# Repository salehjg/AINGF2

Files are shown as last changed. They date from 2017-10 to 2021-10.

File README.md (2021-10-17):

# AINGF2
FPGA Based Digital Still Camera Over USB-2.0  
  
# Hardware
FPGA: Xilinx Spartan-3  
Memory: Cypress SRAM * 2 (seperate busses)  
USB: Cypress USBFX2LP  
  
# Architecture
* Ping-pong frame aquisition by utilizing the both SRAMs and their respective (and seperate) SRAM Controllers 
* 8051 soft-core for reset signal management and I3C custom interface handling.  
* simple hex2coef converter utility to convert built firmware(hex-file) into xilinx-coef format for integrating into ROM IP CORE (on platform-flash)  
  
# PCB
Designed using Altium-Designer as double-sided PCB.  
there are some known issues related to ground bouncing and signal integrity at challenging clock frequencies (PCLK, main clock) which are avoidable by a proper 4-Layer PCB stackup.  
  
# Software
The host program is written in C#.Net to receive data that is sent over USB-2 and to configure the internal registers of the image sensor based on the official SDK for USBFX2LP and the official Cypress driver for Microsoft-Windows.

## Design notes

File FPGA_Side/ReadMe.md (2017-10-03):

# FPGA Side
**Tool:** 		Xilinx ISE 14.7  
**Board:** 		AINGF-V2(PCB project is included in this repository)  
**IP Cores:**	LogiCORE Block Memory Generator Version: 7.3 Rev 1 (RAM, RAMX, ROM), LogiCORE FIFO Generator V9.3 Rev 1, ILA  
**Soft Cores:**	MC8051 V1.6 by Oregano Systems (Firmware @ .\00_Codes\m8051_IP\01_FIRMWARE\01_PRJ - compile with KEIL 8051)  
**Hex2COE:**	Use http://bayanbox.ir/info/3158965663086160332/Converter to convert MC8051's firmware HEX file to Xilinx COE format. Additional information at https://goo.gl/yE7do2  
**Top Module:**	.\00_Codes\Sram_Center\HardTest\TOP_WIRING.v

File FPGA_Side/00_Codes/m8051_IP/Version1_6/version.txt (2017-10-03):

This is version 1.6 of the MC8051 IP core.

March 2010: Oregano Systems - Design & Consulting GesmbH
============================================================
Changes: 
- In certain interrupt situations the stack pointer still 
  has been erroneously set in control_mem_rtl.vhd, revision
  1.10 and below. This has been corrected again in revision
  1.11 of this file.
- The Serial Unit did not handle receives with only one
  stop bit correctly in Mode1 in file mc8051_siu_rtl.vhd,
  revision 1.9 and below. This has been corrected with
  revision 1.10 of this file.
- The CJNE opcode did not clear the carry flag when it 
  should in file control_fsm_rtl.vhd, revision 1.9 and 
  below. This has been corrected with revision 1.10 of this
  file.

************************************************************
This is version 1.5 of the MC8051 IP core.

September 2006: Oregano Systems - Design & Consulting GesmbH
============================================================
Changes: 
- When an interrupt is pending and the instruction executed
  is RETI or a write access to IE or IP one more instruction
  is executed before vectoring to the interrupt routine.
- The synchronization stage of the interrupt inputs in the
  timer/counter unit has been hardended with additional
  series flip-flops due to the high operating frequencies
  nowadays in use.
- A prescaler in the serial interface unit has been changed
  to 1/12 instead of 1/16 to conform to mode 0 databook 
  descriptions.
- The carry flag was incorrectly reset during a special 
  situation. This has been corrected.
- tmr/ctr1 erroneously used his run flag when tmr/ctr0 was
  in mode 3. This has been corrected.
- In certain interrupt situations the stack pointer has 
  been erroneously set. This has been corrected.
============================================================
Oregano Systems - Design & Consulting GesmbH
Phorusgasse 8, A-1040 Vienna

@: mc8051@oregano.at
W: http://oregano.at/ip/8051.htm

************************************************************
This is version 1.4 of the MC8051 IP core.

November 2004: Oregano Systems - Design & Consulting GesmbH
============================================================
Changes:
- corrected behaviour of RETI instruction handling
- added synchronization for interrupt signals
- corrected timer problems

************************************************************
This is version 1.3 of the MC8051 IP core.

September 2002: Oregano Systems - Design & Consulting GesmbH
============================================================
Change history:
- Improved tb_mc8051_siu_sim.vhd to verify duplex operation.
- Corrected problem with duplex operation in file 
  mc8051_siu_rtl.vhd

************************************************************
This is version 1.2. of the MC8051 IP core.

June 2002 - Oregano Systems - Design & Consulting GesmbH
============================================================
Change history:
- Eliminated the scr subdirectory form the distribution.
- Improved documentation.
- Corrected several bugs in the source code (see the
  website for more details).
- Improved the testbench with respect to the I/O port
  behavior.
- Enriched the msim directory with the assembler source
  code of an example program.
- Provided the source code of a Intel hex to binary
  textfile converter to ease simulation of the user's
  assambler programs.

************************************************************
This is version 1.1. of the MC8051 IP core.

Jan 31st 2002 - Oregano Systems - Design & Consulting GesmbH

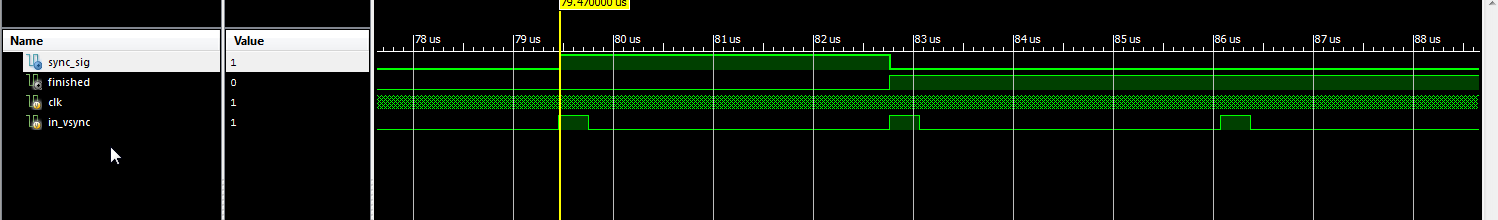
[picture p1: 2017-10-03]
FPGA_Side/00_Codes/Vsync_CTRLR/SIM/2015-10-29 17_59_20-ISim (P.20131013) - [Default.wcfg].png

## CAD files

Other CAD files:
FPGA_Side/00_Codes/m8051_IP/01_FIRMWARE/01_PRJ/Objects/main.obj
FPGA_Side/00_Codes/m8051_IP/01_FIRMWARE/01_PRJ/Objects/delay.obj
FPGA_Side/00_Codes/m8051_IP/01_FIRMWARE/01_PRJ/Objects/core.obj
FPGA_Side/00_Codes/m8051_IP/01_FIRMWARE/01_PRJ/Objects/mem.obj

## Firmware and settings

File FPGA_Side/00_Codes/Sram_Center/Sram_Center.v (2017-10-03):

module sram_center 
(
input clk_fast						,
//input button_capture				,
input button_g_reset				, 	//active low - async
output reset_out					,
output cam_reset_out				,
output out_nrst_usbfx				,
output reset_n_cam_setup_out 		, 	//cemra setup module's active low reset signal(NOT reg_buff's reset)  w_nreset_cam_setup
output reset_reg_buff_out			,
input cam_setup_done_input			,
input reset_release		 			,
input rst_semi						,
//------------------^^^^^	
inout  [15:0]   fdata				,	//FIFO data lines.
output [1:0]    faddr				,	//FIFO select lines
output          slrd				,	//Read control line
output          slwr				,	//Write control line
input           flagd				,	//EP6 Full Flag
input           flaga				,	//EP2 Empty Flag
output          sloe				,	//Slave Output Enable Control    
output 			pktend				,
//------------------^^^^^SRAM1
output [19:0]ad1	 				,	//chip interface - address
output we_n1		 				,	//chip interface - write en
output oe_n1		 				,	//chip interface - output en
inout [15:0]dio_a1	 				,	//chip interface - data bus 
output ce_a_n1		 				,	//chip interface - chip en
output ub_a_n1		 				,	//chip interface - upper byte
output lb_a_n1		 				,	//chip interface - lower byte
//------------------^^^^^SRAM2
output [19:0]ad2					,	//chip interface - address
output we_n2						,	//chip interface - write en
output oe_n2						,	//chip interface - output en
inout [15:0]dio_a2					,	//chip interface - data bus
output ce_a_n2						,	//chip interface - chip en
output ub_a_n2						,	//chip interface - upper byte
output lb_a_n2						,	//chip interface - lower byte

 
//------------------^^^^^	
input pclk							,
input href		 					,
input vsync							,
input [7:0]data						,	
//------------------^^^^^
output reg sccb_buff_n_rst			,
output reg [15:0]sccb_buff_din		,
output reg [5:0] sccb_buff_index	,
output reg sccb_buff_wr_en			,
//------------------^^^^^
output led_over_run					,
output reg led_green				,
output reg led_red					,
output finished						,

//------------------^^^^^
output dbg_fifo_wr_en 				,	
output dbg_fifo_wr_ack				,	
output dbg_fifo_full				,		
output dbg_fifo_overflow			,			
output dbg_rst_logic				,
output dbg_rst_fifo					,
			
output reg [15:0] dbg_fifo_dout		,
output dbg_fifo_rd_en      			,
output dbg_fifo_empty      			,
output dbg_fifo_valid      			,
output dbg_fifo_underflow  			,
 
output dbg_vsync_oneshot			,
output [19:0]dbg_data_cnt			,
input [15:0]dbg_instruction_input

);







/////////////////////////////USB-FX2 SIGNALS////////////////////////////////////////////////////////////////////////////////////////
reg [1:0] 	faddr_i											;
reg [15:0] 	fdata_i					= 16'b00000000			;
reg [15:0] 	temp											;
reg      	slrd_i											;
reg      	slwr_i											;
reg      	sloe_i											;
reg 	 	pktend_i										;
reg [2:0] 	gstate_i										;

assign 		slrd 					= slrd_i				;
assign 		slwr 					= slwr_i				;
assign 		faddr 					= faddr_i				;
assign 		sloe 					= sloe_i				;
assign 		fdata 					= fdata_i				;
assign 		pktend 					= pktend_i				;


////////////////////////////////////////////////////////////////////////////////////////////////////////////////////////////////////
wire 		rst_logic				 						; 
assign 		reset_out 				= rst_logic				;
wire 		rst_camera				 						; 
assign 		cam_reset_out 			= rst_camera			;

wire 		w_nreset_cam_setup 								;  
assign 		reset_n_cam_setup_out	=  w_nreset_cam_setup	;
wire 		w_reset_reg_buff_out							;
assign 		reset_reg_buff_out 	 	= w_reset_reg_buff_out	;

wire 		fifo_rd_en	     								;
wire[15:0]	fifo_dout 										;
wire 		fifo_empty	     								;
wire 		fifo_valid	     								;
wire 		fifo_underflow  								;
reg [15:0]	compare_data									;
reg [15:0]	compare_data_next								;
reg 		rd_en											;
assign 		fifo_rd_en 				= rd_en					;
	
wire 		w_finished										;
assign 		finished 				= w_finished			;
wire 		w_vsync_oneshot									;
assign 		dbg_vsync_oneshot 		= w_vsync_oneshot		;
reg [19:0]	dbg_data_cnt_r									;
assign 		dbg_data_cnt 			= dbg_data_cnt_r		;
reg [15:0] 	dbg_fifo_dout_next								;

reg FSM_B_flag_addr_sampled;		//add to always(posedge)
reg FSM_B_flag_addr_sampled_next; 	//add to always(posedge)

//reg 		rst_semi_r										;
//wire 		rst_semi		 								;
//assign 	rst_semi 			= rst_semi_r				;
//assign 	finished 			= !rst_logic				;


////////////////////////////////////////////////////////////////////////////////////////////////////////////////////////////////////

wire 		Wmem1											;
wire 		Wrw1											;
reg 		rw1   											;
reg 		mem1  											;
assign  	Wrw1  			= rw1							;
assign 	 	Wmem1 			= mem1							;

wire 		Wmem2											;
wire 		Wrw2											;
reg 		rw2   											;
reg 		mem2  											;
assign  	Wrw2  			= rw2							;
assign 	 	Wmem2 			= mem2							;

wire[19:0]	addr1 											;
reg [19:0]	r_addr1 		= 20'hFFFFF						;
reg [19:0]	r_addr_next1 	= 20'hFFFFF						;
assign 		addr1 			= r_addr1						;

wire[19:0]	addr2 											;
reg [19:0]	r_addr2 		= 20'hFFFFF						;
reg [19:0]	r_addr_next2 	= 20'hFFFFF						;
assign 		addr2 			= r_addr2						;

reg [19:0] r_pixel_cnt		= 20'd0							;
reg [19:0] r_pixel_cnt_next	= 20'd0							;

wire[15:0] 	data_f2s1										;
reg [15:0] 	data_f2s_r1										;
assign 		data_f2s1 		= data_f2s_r1					;

wire[15:0] 	data_f2s2										;
reg [15:0] 	data_f2s_r2										;
assign 		data_f2s2 		= data_f2s_r2					;

wire 		w_ready1										;
wire[15:0]	w_data_s2f_r1									;

wire 		w_ready2										;
wire[15:0]	w_data_s2f_r2									;

wire 		read_data_valid = (w_data_s2f_r2 == 16'h00AA)	;

reg [9:0] 	semi_counter									;
//---------------------------------------------------------------
//CODES FOR NEW 2 SRAM CTRLRs
reg arbiter_sel=0;
reg arbiter_sel_next=0;

wire s1Wmem		    ;
wire s1Wrw		    ;
wire [19:0]s1addr		    ;
wire [15:0]s1data_f2s	    ;
wire s1w_ready      ;
wire [15:0]s1w_data_s2f_r	;

wire s2Wmem		    ;
wire s2Wrw		    ;
wire [19:0]s2addr		    ;
wire [15:0]s2data_f2s	    ;
wire s2w_ready      ;
wire [15:0]s2w_data_s2f_r	;


wire [19:0]w_ad1				;
wire w_we_n1					;
wire w_woe_n1					;
wire [15:0]w_dio_a1				;
wire w_ce_a_n1   				;
wire w_ub_a_n1   				;
wire w_lb_a_n1   				;

assign ad1		=	w_ad1		;
assign we_n1	=	w_we_n1		;
assign oe_n1	=	w_woe_n1	;
assign dio_a1	=	w_dio_a1	;
assign ce_a_n1	=	w_ce_a_n1   ;
assign ub_a_n1	=	w_ub_a_n1   ;
assign lb_a_n1	=	w_lb_a_n1   ;


wire [19:0]w_ad2				;
wire w_we_n2					;
wire w_woe_n2					;
wire [15:0]w_dio_a2				;
wire w_ce_a_n2   				;
wire w_ub_a_n2   				;
wire w_lb_a_n2   				;

assign ad2		=	w_ad2		;
assign we_n2	=	w_we_n2		;
assign oe_n2	=	w_woe_n2	;
assign dio_a2	=	w_dio_a2	;
assign ce_a_n2	=	w_ce_a_n2   ;
assign ub_a_n2	=	w_ub_a_n2   ;
assign lb_a_n2	=	w_lb_a_n2   ;


////////////////////////////////////////////////////////////////////////////////////////////////////////////////////////////////////
parameter C0=3'd0,C1=3'd1,C2=3'd2,C3=3'd3,C4=3'd4;
reg [2:0] 	Cstate		, Cstate_next;
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

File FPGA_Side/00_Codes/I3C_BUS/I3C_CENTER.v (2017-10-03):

/*======================================================================*
**	I3C_CENTER Module.
**
*************************************************************************	
*************************************************************************
**	
**	Desc.:	This module monitors I3C_BUS and manage requests and responds
**			with desired data-word(16 bits).
**			this module produces sync-triggers for external modules on 
**			system within different clock domains of clk_fast & clk_slow.
**
*************************************************************************
*************************************************************************
**
**  w_parallel_dout Structure:
**		{ MSbyte,LSbyte}
**		MSbyte: M-nibble: group code   L-nibble: subcode
**		LSbyte: data
**
**
//======================================================================*/


module I3C_CENTER
(
	input rst	  ,
	input clk_fast,	
	input clk_slow, //should be PCLK

	
	
	input 		bus_clk		,
	output  	bus_dout	,
	input 		bus_din		,
	
	
	
	output  	o_trig_async_g_nrst			, 	//  -global reset 		- activeLOW 	- ASYNC
	output reg 	o_trig_pclk_semi_rst		, 	//  -semi reset 		- activeHIGH 	- pclk		/posedge
	output  	o_trig_pclk_reset_release	, 	//  -reset release		- activeLOW 	- pclk		/posedge
	output 		o_trig_async_cam_setup_nrst ,	//  -cam_setup_nrst		- activeLOW 	- ASYNC

	output  	buff_port_wr	            ,   //output synced by module   buff_port_wr_synced
	output  	buff_port_rd	            ,   //output synced by module   buff_port_rd_synced
	
	input 		[15:0]	buff_port_dout	   	,
	output reg 	[15:0]	buff_port_din	   	,
	output reg 	[5:0]	buff_port_indx	   	,
	

	
	output			dbg_data_ready,
	output 			dbg_I3C_CTRLR_state,
	output [3:0]	dbg_state
	
);

//======================================================================
parameter 	group_reset_control				= 4'd1;
			parameter	subcode_reset_semi	= 4'd1;
			parameter	subcode_reset_deep	= 4'd2;
			
			
parameter	group_aquire_control			= 4'd2;
			parameter	subcode_aquire_send = 4'd1;
			parameter	subcode_sccb_commit = 4'd2;
			
			
parameter	group_sccb_mono					= 4'd3;


parameter	group_sccb_burst_w				= 4'd4;
			parameter	subcode_burst_w_start = 4'd1;
			parameter	subcode_burst_w_loop0 = 4'd2;
			parameter	subcode_burst_w_loop1 = 4'd3;
			parameter	subcode_burst_w_stop  = 4'd4;

parameter	group_sccb_burst_r				= 4'd5;
			parameter	subcode_burst_r_start = 4'd1;
			parameter	subcode_burst_r_loop0 = 4'd2;
			parameter	subcode_burst_r_loop1 = 4'd3;
			parameter	subcode_burst_r_stop  = 4'd4;
			

//======================================================================
parameter 	opcode_modify_sccb_buffer_address 	= 8'b000_00001 ,
			opcode_modify_sccb_buffer_data		= 8'b000_00010 ,
			opcode_modify_sccb_commit			= 8'b000_00011 ,
			opcode_aquire_single_frame_and_send = 8'b000_01000 , //0x08
			opcode_reset_entire					= 8'b000_01010 , //0x0A
			opcode_reset_semi					= 8'b000_01011 ; //0x0B
//======================================================================
localparam S0  = 4'D0 ;
localparam S1  = 4'D1 ;
localparam S2  = 4'D2 ;
localparam SS3 = 4'D3 ;
localparam SS4 = 4'D4 ;
localparam SS5 = 4'D5 ;
localparam SS6 = 4'D6 ;
localparam SS7 = 4'D7 ;
localparam S8  = 4'D8 ;
localparam S9  = 4'D9 ;
localparam S10 = 4'D10;
localparam S11 = 4'D11;
localparam S12 = 4'D12;
localparam S13 = 4'D13;
localparam S14 = 4'D14;
localparam S15 = 4'D15;

reg	[3:0] state=0;
assign dbg_state = state;

//======================================================================
wire w_data_ready; assign dbg_data_ready = w_data_ready;
reg [15:0]  parallel_din;
//reg [15:0]  parallel_din_next;
wire [15:0] w_parallel_dout;
reg r_trig_async_g_nrst = 1'b1; assign o_trig_async_g_nrst = r_trig_async_g_nrst;
reg r_trig_pclk_reset_release = 1'b1; assign o_trig_pclk_reset_release = r_trig_pclk_reset_release;
reg r_trig_async_cam_setup_nrst = 1'b1; assign o_trig_async_cam_setup_nrst = r_trig_async_cam_setup_nrst;
reg i3c_bus_rst=0;


//reg [15:0] buff_port_din_next;
//reg [5:0]  buff_port_index_next;
//======================================================================
I3C_BUS I3C001
(
	.rst		(i3c_bus_rst) ,
	.bus_clk	(bus_clk ),
	.bus_dout	(bus_dout),
	.bus_din	(bus_din ),
	//---------------------
	.parallel_din(parallel_din),
	.parallel_dout(w_parallel_dout),
	//---------------------
	.data_ready(w_data_ready), 					//asyc-output WARNING!
	//---------------------
	.dbg_state(dbg_I3C_CTRLR_state)
);

//======================================================================
reg buff_port_wr_synced=0;
sync sync_wr
(
	.clk_fast_dest(clk_fast)					,
	.clk_slow_src() 							,
	.flag_in_active_high(buff_port_wr_synced)	,
	.flag_out_active_high(buff_port_wr)		
);
//======================================================================
reg buff_port_rd_synced=0;
sync sync_rd
(
	.clk_fast_dest(clk_fast)					,
	.clk_slow_src() 							,
	.flag_in_active_high(buff_port_rd_synced)	,
	.flag_out_active_high(buff_port_rd )		
);

//======================================================================
reg instruction_done = 0;

//======================================================================
always@(posedge clk_slow or posedge rst)
begin
	if(rst)
	begin
		state = 0;
		instruction_done = 0;
		
		r_trig_async_g_nrst 		= 1'b1; //active low
		o_trig_pclk_semi_rst		= 1'b0; //active high
		r_trig_pclk_reset_release 	= 1'b1; //active low	
		r_trig_async_cam_setup_nrst	= 1'b1; //active low	
		
		i3c_bus_rst = 1'b1;
		
		buff_port_rd_synced = 1'b0;
		buff_port_wr_synced = 1'b0;
		
		buff_port_din	=0;
		buff_port_indx	=0;
		parallel_din	=0;
	end
	else
	begin
		i3c_bus_rst = 1'b0;
		if(w_data_ready==0)
		begin
			instruction_done = 0;
		end




		///////////////////////////////////////
		r_trig_async_g_nrst 		= 1'b1; //active low
		o_trig_pclk_semi_rst		= 1'b0; //active high
		r_trig_pclk_reset_release 	= 1'b1; //active low
		r_trig_async_cam_setup_nrst	= 1'b1; //active low
		
		//-------------------------------------
		buff_port_rd_synced = 1'b0;	        //active low
		buff_port_wr_synced = 1'b0;	        //active low
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
